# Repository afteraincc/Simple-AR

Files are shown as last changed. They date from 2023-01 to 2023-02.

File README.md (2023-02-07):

>
> 视频介绍：[Simple-AR百元AR眼镜](https://www.bilibili.com/video/BV1hj411M7NZ)
>

### 简介

一个`百元价位`的AR眼镜，用来学习了解AR的技术原理。基本流程：AR眼镜作为一个简单的显示设备，通过手机的`个人热点`连接到手机，然后手机通过`4G/5G`网络访问`互联网`，把需要的内容提供给AR眼镜显示出来。



AR眼镜粗略可分为几个子模块：

- 显示

	显示屏最好是既要分辨率高/亮度高/对比度高/色彩还原度高，又要体积小，还要耗电低/价格低。实际最后选择就一个：价格低...

- 光学

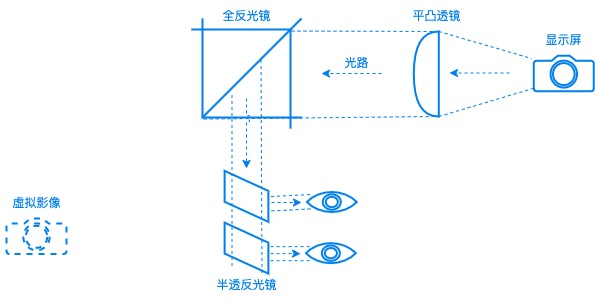
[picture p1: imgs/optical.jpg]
	

	- 平凸透镜

		原理是利用对点光源的准直`Collimating Light`特性，效果是可以避免影像重叠`Double Image Problem`。

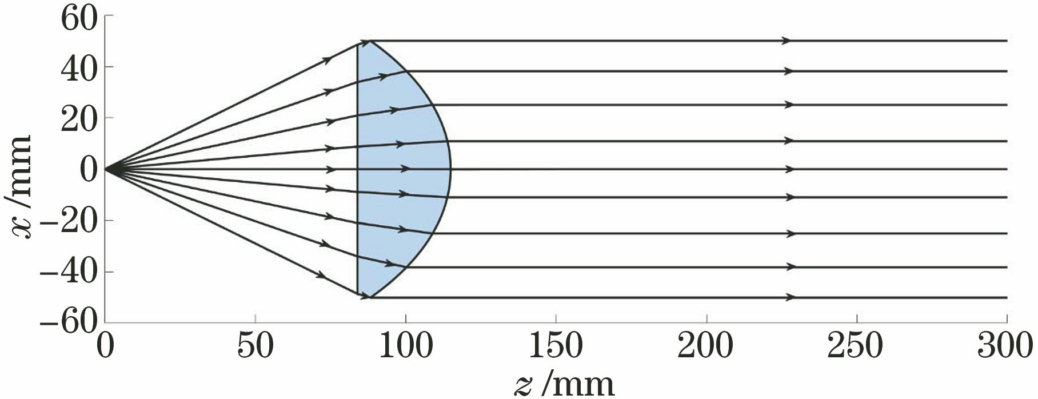
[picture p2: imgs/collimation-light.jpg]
		

		需要注意两点：
		
		- 安装时不要反了，遵循`点光对平面`：显示屏=>|平面/凸面)=>全反光镜

		- 透镜的位置：在保证显示区域的范围下尽量靠近焦点，这样准直光效果更好。但是也不能放在焦点上，否则无法成像...

	- 全反光镜

		为了避免影像重叠，最好采用单面镜`First Surface Mirrors`，而不是普通的玻璃镜`Second Surface Mirrors`。

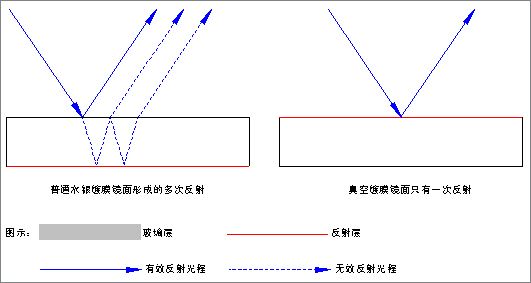
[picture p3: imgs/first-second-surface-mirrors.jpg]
		

	- 半透反光镜

		AR和VR的区别：AR既可以看到虚拟的影像，也可以看到真实的世界。镜片的厚度尽可能小，也可以避免重影现象。

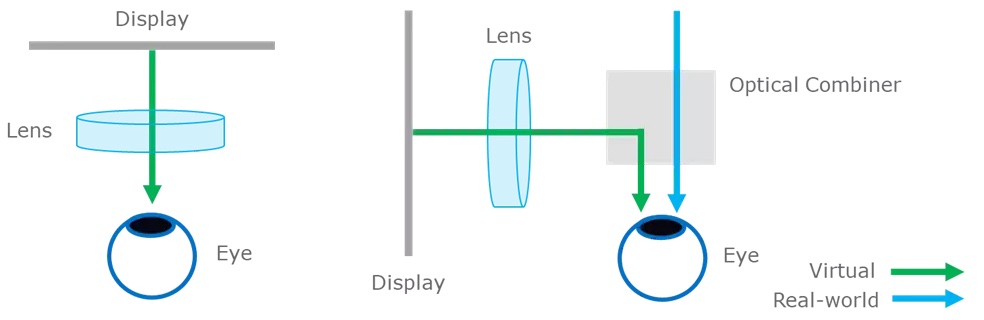
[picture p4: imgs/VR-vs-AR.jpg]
		
		
		注意的是：每个眼镜都对应一个半透反光镜。可以通过调整两个半透反光镜的角度，让虚像重叠形成立体图像效果。如果仅仅只有一个单眼观看时，容易出现不完整的图像现象，并且没有立体效果。

	- 比较一下苹果的专利方案

		使用了光波导`Waveguide`镜片，光路的原理都是一样的（显示=>准直光=>全反光=>半透反光）。

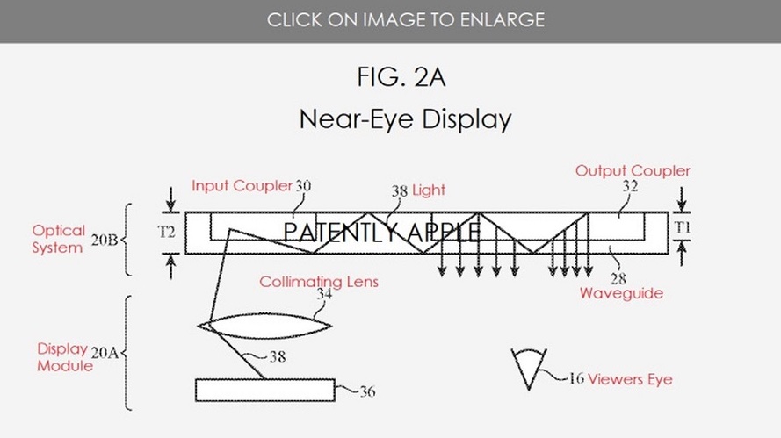
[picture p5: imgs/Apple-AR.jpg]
		

		光波导集成了全反光镜和半透反光镜，同时提供了一些新特性（例如一维/二维扩瞳技术提高视场角`FOV`）。

- 算力

	计算模块提供屏幕显示/图像压缩/无线传输等各种功能。一般用嵌入式设备，这样可以按需配置算力大小，以便压缩成本/定制尺寸。

- 电力

	穿戴设备面向移动场景，对电量的需求是越大越好，尺寸越小越好。

- 外框

	主要作用是固定各个组件以及方便的佩戴，在固定组件的位置时注意保证光路的中心对齐。使用3D打印技术能极大的降低成本。

### 材料清单和价格

都是选择淘宝上可以方便买到的东西，量足价低。

| 组件 | 价格（元） | 描述 |
| --- | --- | --- |
| 显示屏 | 17 | 1.3寸IPS屏240x240像素，SPI串口，ST7789驱动 |
| 平凸透镜 | 9.9 | 直径25mm焦距90mm |
| 全反光镜 | 8.5 | 软镜子/PVC镜面 50x50cm，实际只需要4.2x4.0cm |
| 半透反光镜 | 12.5 | 用显微镜的1mm载玻片(12.5元/50片)，也可以用更薄的0.15mm盖玻片（非常脆容易碎）  |
| 算力 | 19.5 | 开发板：NodeMCU-32S兼容Arduino，芯片模组：ESP-WROOM-32E |
| 框架 | 70 | 白色树脂3D打印 |
| 杜邦线 | 2 | 母对母 40根（实际使用8根） |
| 螺丝/螺母 | 4 | 亚克力材质 3x10mm 10套 |
| 总价 | 143.4 | |

### 值得改进的地方

其实每个部分都有非常大的改进空间，当然最后就是价格赶超各款在销的AR眼镜了。这个和项目的定位`百元价位`是冲突的，所以这些改进的地方也只是说说而已，并不会真正去改进的...

- 光学显示

	- 显示屏

		更高分辨率/更小尺寸。但是价格的增加不是一点点...240x240像素1.3寸IPS屏之只要17元，1920x1080像素0.39寸的OLED屏需要300～500元

	- 光波导`Waveguide`镜片

		重量轻，而且能提供更大的FOV。在alibaba.com搜索集成了显示屏的模组，1024x768分辨率要450刀，1920x1080分辨率要680刀...

	（显示区域原理： 焦距/直径）
光学显示系统（焦距固定/FOV/亮度等）/算力

	- 3D立体

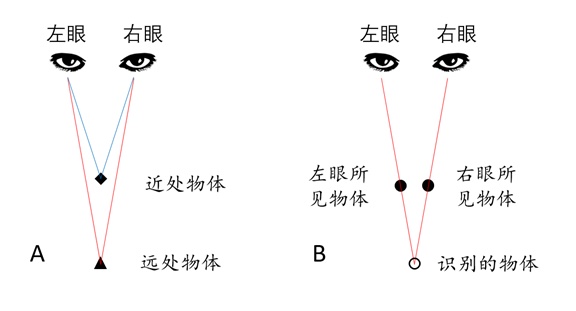
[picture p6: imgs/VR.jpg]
		

		人眼看到3D物体时，实际上左右眼看到的内容不一样，最后是通过大脑合成3D效果的。所以需要左右2路独立的显示模块，当然也需要更多的算力来生成相似但又有差异的画面，也需要更多的电力。
		
	- 混合现实`MR`

		大部分AR眼镜都是定焦成像，而眼睛的焦距调整范围比较广，如果看东西的焦距和眼镜的焦距差距比较大时，只能看到模糊的虚拟影像。
		
		- 可变焦距

			要清晰显示又贴近实物，就要集成可变/可调焦距的光学模块，有些类似手机/摄像机的自动对焦。

		- 眼球跟踪

			自动调焦配合眼球跟踪才能真正实现自动对焦。

	- 眼镜框

		另外树脂材料较软容易变形，可以考虑用硬度更高的尼龙材料，当然价格就要翻几倍了...

		为了方便携带，可以参考普通眼镜的结构（鼻托/耳架等）。为了美观，可以考虑加入钛合金，增加喷砂工艺，效果上升不止一个等级，当然价格也上升不止一个等级...

### 更实际一些的应用场景

**以下是纯属没有根据的瞎分析**

**主要是几点 1. 去掉内置电池 2. 有线替代无线 3. 眼镜只做显示设备，4. 算力需求移到人人都有/算力过剩的手机上。这样可以节省不少成本，也能减少体积，重量也更轻**

现在的AR眼镜价位在2～4千元，还主要是给第一批资金充足的尝鲜用户准备的。真要大规模推广，还是需要价格上相当的降低才行。所以可以考虑找一些要求不高，但是又有规模的用户场景来推广。

- 汽车HUD显示

	可玩性：有固定的电源，眼镜和手机都不需要考虑电不够的情况。而且手机作为算力来源，可玩性高太多了，手机上有非常成熟的语音控制/辅助驾驶/AR/VR等等各种现成的东西可用。

	价格：价格上应该比厂商集成的挡风玻璃（好几千）的便宜，还有一类外置的HUD价格也要500～1500。

	规模：公开市场分析估计各类的汽车HUD一年都有好几百万的销量，而且还在快速增长，还是有足够空间的

- 无人机HUD显示

	可用性：室外玩时已经带了一堆设备，无所谓多带一个高容量的充电宝了:-)
	
	价格：玩无人机的用户应该能接受稍贵一些的外设
	
	规模：估计大疆一家累计的就有几百万了吧？

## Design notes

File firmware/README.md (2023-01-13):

### 简介

需要有WIFI功能的嵌入式芯片，ESP32芯片是带WIFI功能中最常用的一款了。另外开发板选择了NodeMCU-32S，主要是兼容Arduino，资料多，方便开发。

### 网络连接流程

流程的关键步骤是`反向连接`：嵌入式设备非常不方便输入，所以由AR设备生成`个人热点`的SSID和密码，手机按照这个来配置热点。

- 如何重置`个人热点`配置

	先按`RESET`按键复位，然后快速按`IO0`按键，会重置配置，配置会显示在屏幕上。

### 内存

显示屏分辨率240x240，一张图需要的内存量： 240x240x2=115200字节。ESP32无法分配出这样大小的连续内存...（有方法能实现的，但是要魔改底层模块代码），所以无法使用常见的双帧方案来提高刷新率/并行处理。

### 性能

ESP32的性能对图像处理来说是不够的，测试下来解码240x240的JPEG也就8帧左右。

改成直接传输未压缩BMP图片，发现瓶颈出现在WIFI速率上，未优化的简单测试只能4帧/秒，3.5Mbps左右。查了一下[官方文档](https://docs.espressif.com/projects/esp-idf/en/latest/esp32/api-guides/wifi.html#esp32-wi-fi-throughput)能到20Mbps，但是需要重新编译内核参数等复杂操作。

### 视频流协议

ESP32的性能/内存等不满足一般的视频压缩流（例如MP4/H264等），选择最简单的MJPEG，实际上就是一张一张连续的JPEG图片。需要注意的是JPEG是一种压缩算法，压缩的码流数据要使用容器或文件格式进行 封装后保存或传输，参考[JFIF](https://www.w3.org/Graphics/JPEG/)

在传输的数据流中识别两种图片边界的关键点是JFIF规范了：

- 开头SOI`Start Of Image`对应十六进制 0xFFD8

- 结尾EOI`End Of Image`对应十六进制 0xFFD9

### 跳帧处理

主要还是内存不足（参考前面的`内存`部分）。JPEG的一般压缩率是10:1，但是最终是和图像复杂度有关系，内存申请上要稍微冗余多一点。即使这样也无法完全保证不出现不够的情况。

所以增加了跳帧的处理，如果JPEG图像过大时忽略。

方案选择的是在设备端实现，超出申请的内存时，从开头覆盖内存，但是保持结尾EOI的处理。而不是手机压缩时判断超出尺寸后忽略，避免耦合问题。

### 显示驱动TFT_eSPI库

配置分辨率/管针脚序号等时，官方提供的默认方案是修改库代码。这个方案对代码管理不友好，从上游更新一次代码，就需要记住手工修改一次库代码。

官方提供了另外一个较好的解决方案，任意目录下增加一个固定文件名`tft_setup.h`的配置文件。但是这个需要修改工程的编译参数才能实现，不同的IDE有不同的配置方法，所以最后在IDE层面又不统一了...

- Visual Studio Code + platformio

	配置文件`platformio.ini`增加`build_flags = -I include/tft`，然后`tft_setup.h`放在`include/tft`目录下

### TJpg_Decoder库

Visual Studio Code + platformio提供的TJpg_Decoder库版本非常低（只有0.2.0版本），代码中有inline函数，然后编译器无法兼容这种语法。这个库的新版本是解决了这个问题的，所以需要手工安装：同步TJpg_Decoder最新代码到`lib/TJpg_Decoder`目录即可

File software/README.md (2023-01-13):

### 简介

AR眼镜能看到手机屏幕上的任何内容。流程是录制手机屏幕，经过JPEG压缩，TCP协议传输到AR眼镜上，然后解压缩显示。

### 通用

- 屏幕尺寸

	AR眼镜的显示屏是240x240正方形，手机屏幕都是长方形，而且分辨率远高于240x240。所以只能截取部分屏幕（仅支持竖屏）：以短边（宽）作为正方形边，裁切手机上半部分的正方形内容，然后等比例缩放到240x240分辨率

- 个人热点

	手机开启热点

### Android

- 热点状态

	使用WifiManager实现

- 悬浮窗口

	申请悬浮窗口权限时，调用startActivityForResult，参数：Settings.ACTION_MANAGE_OVERLAY_PERMISSION。

- 录制屏幕

	使用MediaProjectionManager/MediaProjection/VirtualDisplay/ImageReader结合一个后台的IntentService来实现。
	
	Android的录制机制中，Service线程和屏幕数据线程不是一个，只要在函数`onHandleIntent`中实现截图/裁切/缩放/压缩/TCP发送的逻辑即可，其中的阻塞操作并不会影响屏幕数据（个人理解只是截图的acquireLatestImage一瞬间做了线程同步，确保正确采集到屏幕数据）

- 后台服务

	录制屏幕中有阻塞的TCP网络传输，需要使用Android的IntentService服务（普通的Service不能用耗时的阻塞操作）。

- Min SDK Version = 23

### iOS

- 个人热点

	iOS开启热点时，需要有SIM卡，并且运营商开通了热点权限。所以无SIM卡的手机就无法使用了。
	
	iOS热点不能直接配置，默认是手机名。所以如果要配置成AR眼镜的SSID，需要在`设置`=>`关于手机`=>`名称`进行修改。

	另外，iOS查询热点状态需要特殊扩展，个人账号（非开发者账号）没有权限使用，示例中只是写了代码，并没有验证。

- iOS Development Target = iOS 14.0

- 录制屏幕

	iOS的录制屏幕机制和Android不一样，更多的是类似视频流的机制，无论是否阻塞，屏幕数据流会按照固定速率（例如30帧/秒）持续发送到processSampleBuffer回调函数。如果在processSampleBuffer阻塞了，后续的屏幕数据都还在，就会导致帧的堆积，越来越慢。

	而且iOS网络库提供的NWConnection也是异步的机制，所以录制屏幕就不能用Android的同步阻塞机制，需要用`状态机`+`事件`的异步机制实现。

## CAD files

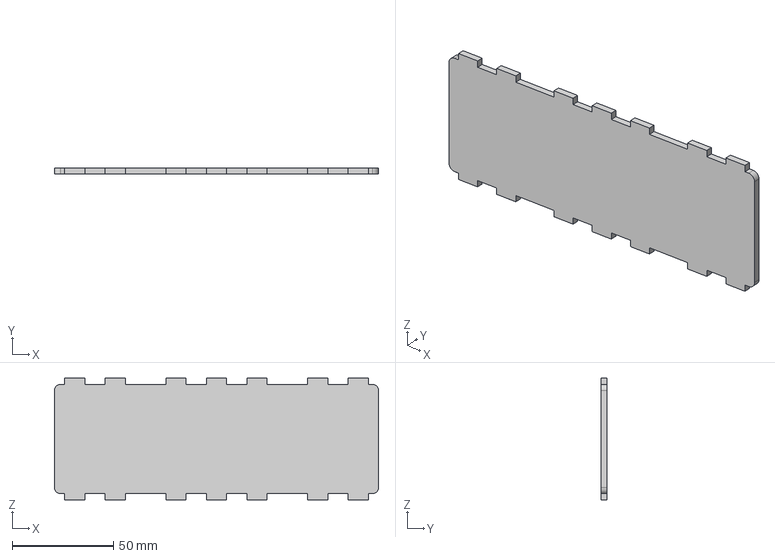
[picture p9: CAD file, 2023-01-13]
3d-model/debug/right.step
160.0 x 3.00 x 60.0 mm

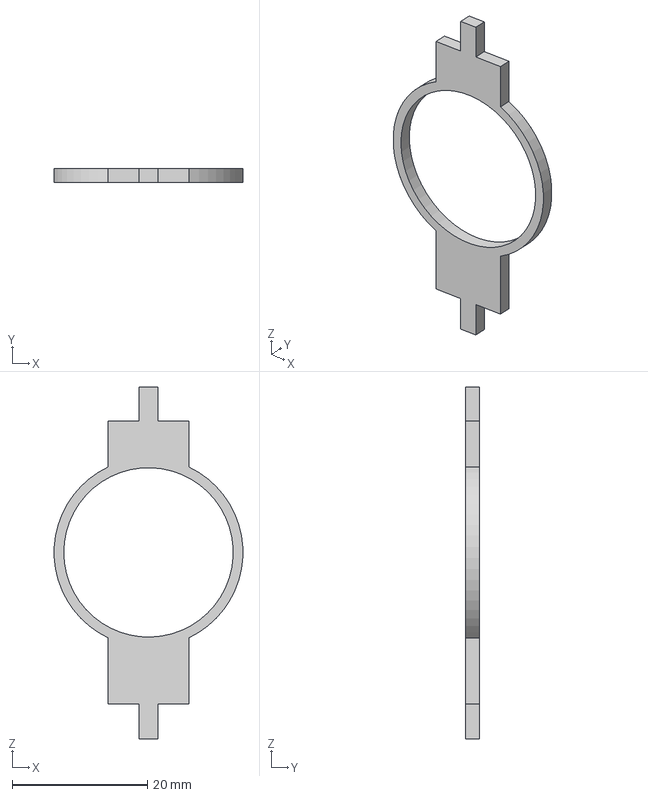
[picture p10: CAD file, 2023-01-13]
3d-model/lens.step
27.9 x 2.00 x 52.0 mm

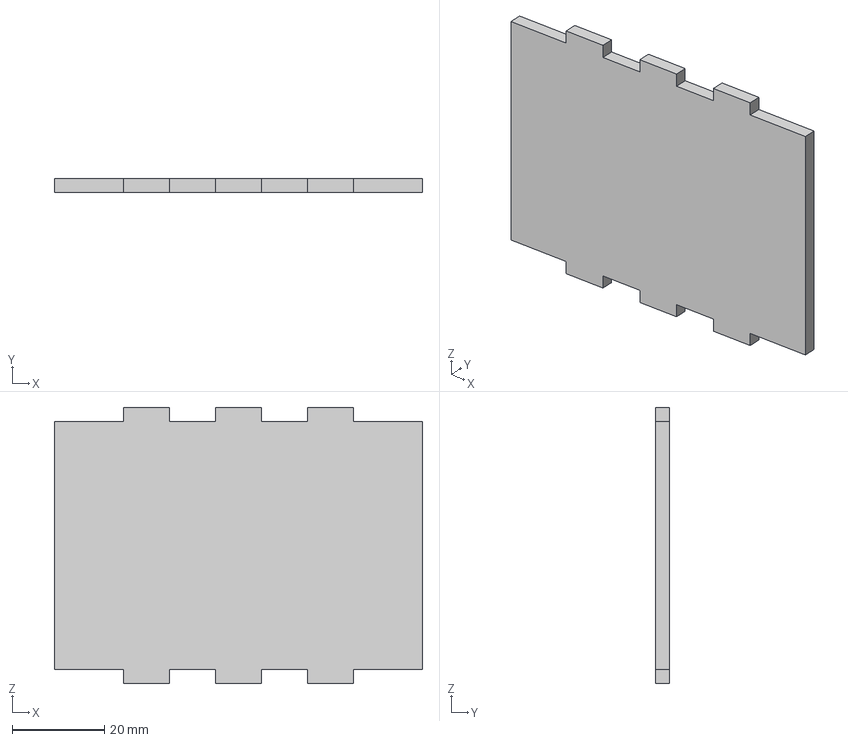
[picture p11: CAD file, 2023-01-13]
3d-model/debug/ear-right.step
80.0 x 3.00 x 60.0 mm

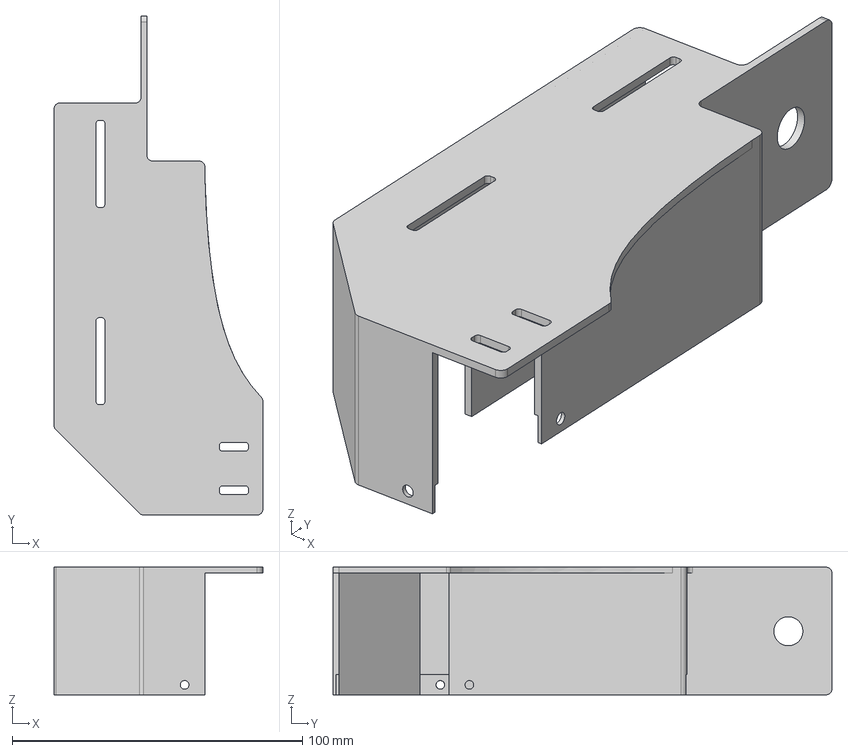
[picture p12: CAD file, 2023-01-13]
3d-model/right-top.step
72.0 x 172.0 x 44.0 mm

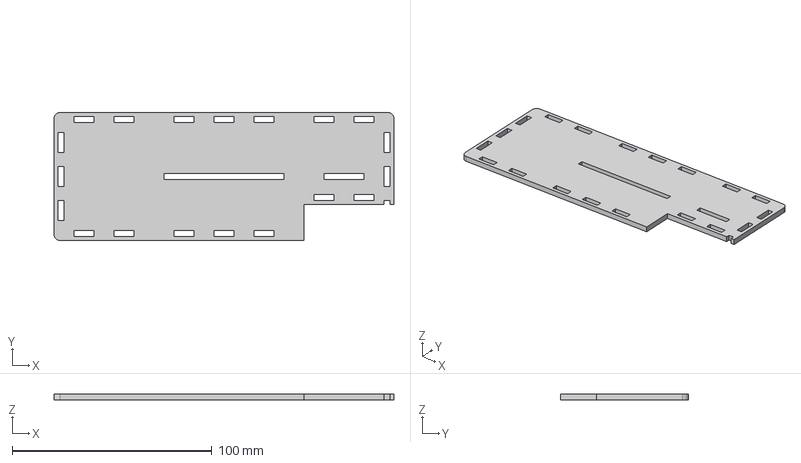
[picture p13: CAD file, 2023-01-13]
3d-model/debug/bottom.step
170.0 x 64.0 x 3.00 mm

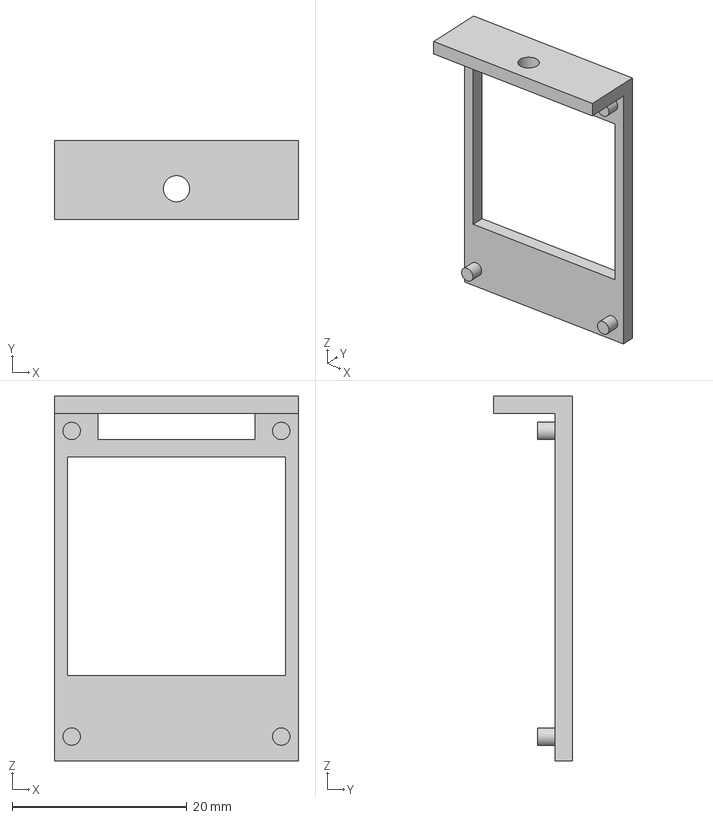
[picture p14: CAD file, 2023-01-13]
3d-model/display.step
28.0 x 9.00 x 41.8 mm

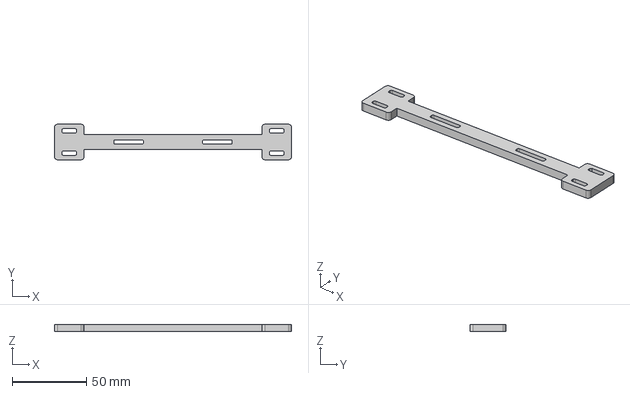
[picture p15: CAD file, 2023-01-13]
3d-model/beam-top.step
160.0 x 24.0 x 5.00 mm

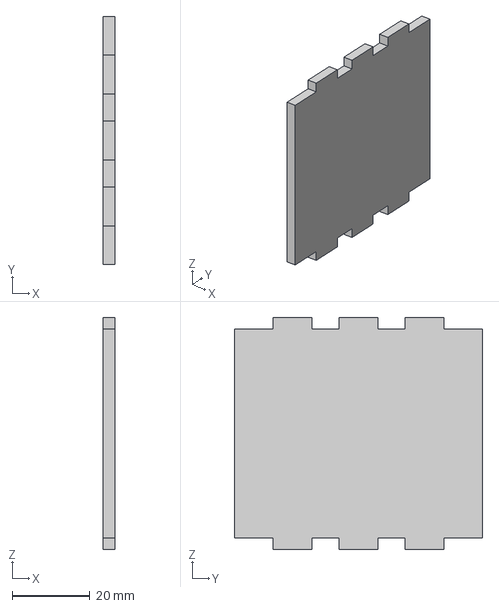
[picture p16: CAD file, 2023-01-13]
3d-model/debug/front.step
3.00 x 64.0 x 59.9 mm

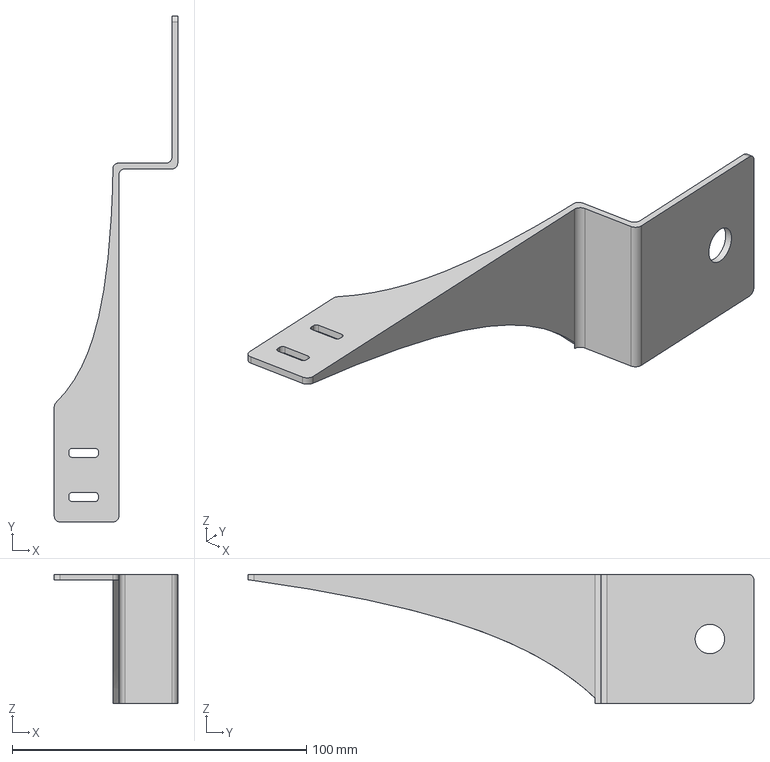
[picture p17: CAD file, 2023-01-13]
3d-model/left.step
42.0 x 172.0 x 44.0 mm

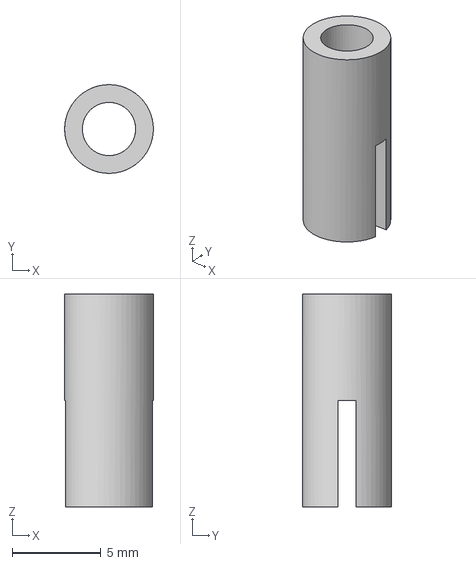
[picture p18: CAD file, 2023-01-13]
3d-model/beam-column-left.step
5.00 x 5.00 x 12.0 mm

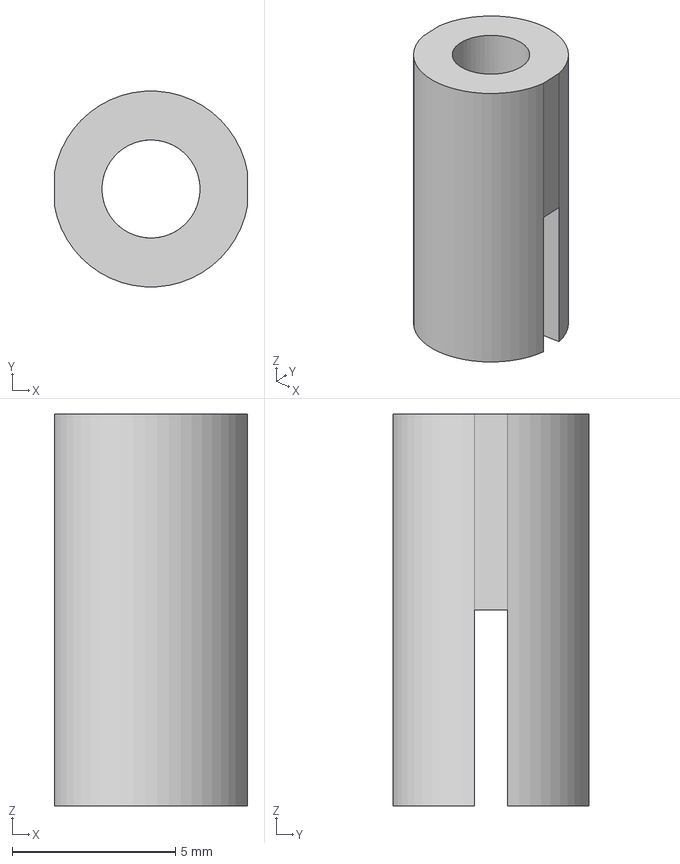
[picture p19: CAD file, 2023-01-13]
3d-model/debug/beam-column-1.step
5.92 x 5.99 x 12.0 mm

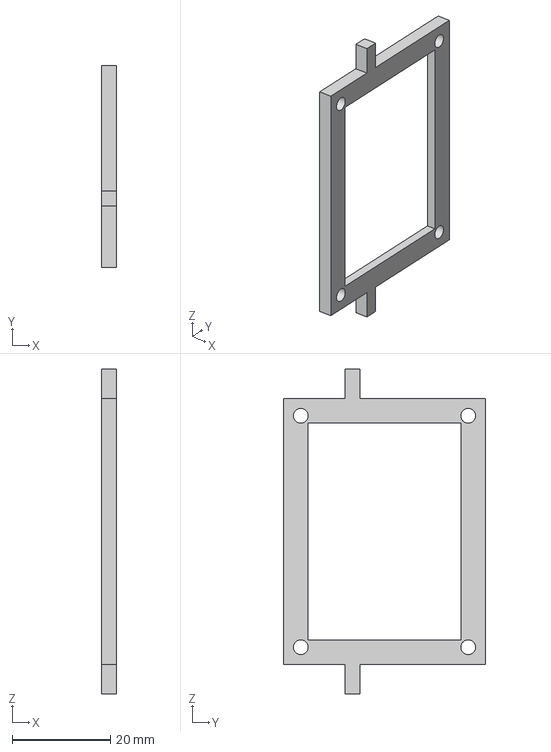
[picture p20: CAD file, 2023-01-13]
3d-model/debug/display-2.step
3.00 x 41.0 x 66.0 mm

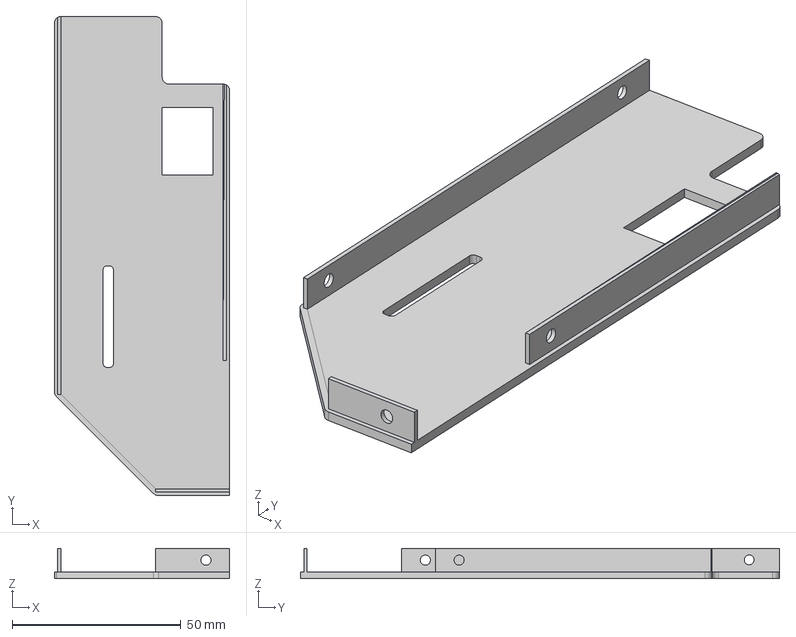
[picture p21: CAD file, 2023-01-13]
3d-model/right-bottom.step
52.0 x 142.0 x 9.00 mm

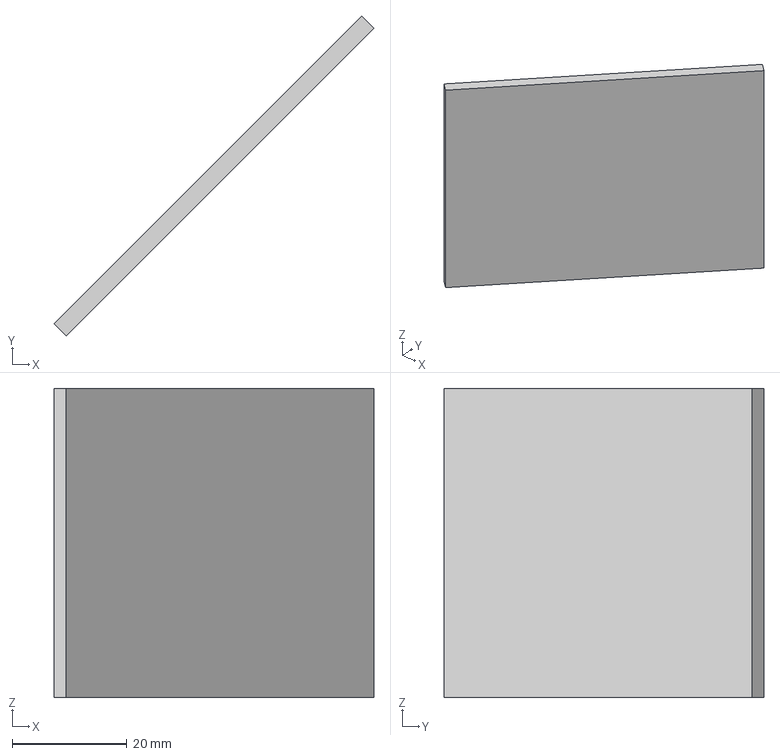
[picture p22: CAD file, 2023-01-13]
3d-model/debug/mirror.step
55.9 x 55.9 x 54.0 mm

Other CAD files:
3d-model/debug/ear-left.step
3d-model/beam-column-right.step
3d-model/debug/top.step
3d-model/debug/lens-2.step
3d-model/debug/back.step
3d-model/debug/beam-column-2.step
3d-model/debug/beam-top.step
3d-model/debug/display-1.step
3d-model/debug/display-beam.step
3d-model/debug/ear-bottom.step
3d-model/debug/ear-top.step
3d-model/debug/left.step
3d-model/debug/lens-1.step
3d-model/debug/lens-beam.step

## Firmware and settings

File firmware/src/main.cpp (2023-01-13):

#include <Arduino.h>
#include "tft_setup.h"
#include <TFT_eSPI.h>
#include <Esp.h>
#include <TJpg_Decoder.h>
#include <Preferences.h>
#include "frame_receiver.h"

static TFT_eSPI tft;
static WiFiServer server;

static String wifiName;
static String wifiPasswd;

static FrameReceiver *frameReciver = NULL;
static unsigned long recvTime = 0;

void echoSystemInfo()
{
  Serial.printf("chip revision: %d\n", ESP.getChipRevision());
  Serial.printf("chip model: %s\n", ESP.getChipModel());
  Serial.printf("chip cores: %d\n", ESP.getChipCores());
  Serial.printf("cpu FreqMHz: %d\n", ESP.getCpuFreqMHz());
  Serial.printf("sdk version: %s\n", ESP.getSdkVersion());

  Serial.printf("heap size: %d\n", ESP.getHeapSize());
  Serial.printf("free heap: %d\n", ESP.getFreeHeap());
  Serial.printf("mini free heap: %d\n", ESP.getMinFreeHeap());
  Serial.printf("max alloc heap: %d\n", ESP.getMaxAllocHeap());

  Serial.printf("psram size: %d\n", ESP.getPsramSize());
  Serial.printf("free psram: %d\n", ESP.getFreePsram());
  Serial.printf("mini free psram: %d\n", ESP.getMinFreePsram());
  Serial.printf("max alloc psram: %d\n", ESP.getMaxAllocPsram());
}

bool needConfigWiFi()
{
  return !digitalRead(KEY_BUILTIN);
}

void configWiFi()
{
  Preferences prefs;
  int r;
  prefs.begin("SimpleAR");

  wifiName = prefs.getString("WiFiName");
  wifiPasswd = prefs.getString("WiFiPasswd");
  if (needConfigWiFi() || wifiName.isEmpty() || wifiPasswd.isEmpty())
  {
    randomSeed(millis());

    wifiName = "AR-";
    // A-Z 65-90, a-z 97-122
    r = random(65, 90 - 4);
    for (int i = 0; i < 4; i++)
      wifiName += (char)(r + i);

    wifiPasswd = "";
    for (int i = 0; i < 4; i++)
    {
      r = random(97, 122);
      wifiPasswd += (char)(r);
      wifiPasswd += (char)(r - (97 - 65));
    }

    prefs.putString("WiFiName", wifiName);
    prefs.putString("WiFiPasswd", wifiPasswd);
  }

  prefs.end();
}

void displayWiFiProgress(const char *name, const char *passwd, int retryCount)
{
  int fontSize = 2;
  int lineHeight = fontSize * 8;
  int startX = tft.width() / 2;
  int startY = tft.height() / 2 - lineHeight;
  String t;

  tft.fillScreen(tft.color565(25, 25, 25));
  tft.setTextDatum(MC_DATUM);
  tft.setTextColor(TFT_WHITE, tft.color565(25, 25, 25));
  t = "WiFiName: ";
  t.concat(name);
  tft.drawString(t, startX, startY, fontSize);
  t = "WiFiPasswd: ";
  t.concat(passwd);
  tft.drawString(t, startX, startY + lineHeight, 2);
  t = "Retrying: ";
  t.concat(retryCount);
  tft.drawString(t, startX, startY + lineHeight * 2, 2);
}

void displayWiFiIP(const char *name, const char *passwd, const char *gateway, const char *ip)
{
  int fontSize = 2;
  int lineHeight = fontSize * 8;
  int startX = tft.width() / 2;
  int startY = tft.height() / 2 - lineHeight;
  String t;

  tft.fillScreen(tft.color565(25, 25, 25));
  tft.setTextDatum(MC_DATUM);
  tft.setTextColor(TFT_WHITE, tft.color565(25, 25, 25));
  t = "WiFiName: ";
  t.concat(name);
  tft.drawString(t, startX, startY, fontSize);
  t = "WiFiPasswd: ";
  t.concat(passwd);
  tft.drawString(t, startX, startY + lineHeight, 2);
  t = "Gateway: ";
  t.concat(gateway);
  tft.drawString(t, startX, startY + lineHeight * 2, 2);
  t = "IP: ";
  t.concat(ip);
  tft.drawString(t, startX, startY + lineHeight * 3, 2);
}

void connectWiFi()
{
  int retryCount = 0;
  WiFi.mode(WIFI_STA);
  WiFi.begin(wifiName.c_str(), wifiPasswd.c_str());

  Serial.println("Waiting for WiFi");
  Serial.println("name: " + wifiName);
  Serial.println("passwd: " + wifiPasswd);
  displayWiFiProgress(wifiName.c_str(), wifiPasswd.c_str(), retryCount);
  while (WiFi.status() != WL_CONNECTED)
  {
    delay(2000);
    Serial.print(".");
    retryCount++;
    displayWiFiProgress(wifiName.c_str(), wifiPasswd.c_str(), retryCount);
  }
  Serial.println("");
  Serial.println("WiFi connected.");

  Serial.print("Gateway: ");
  Serial.println(WiFi.gatewayIP());
  Serial.print("IP Address: ");
  Serial.println(WiFi.localIP());

  displayWiFiIP(wifiName.c_str(), wifiPasswd.c_str(),
                WiFi.gatewayIP().toString().c_str(),
                WiFi.localIP().toString().c_str());
}

bool tft_output(int16_t x, int16_t y, uint16_t w, uint16_t h, uint16_t *bitmap)
{
  if (y >= tft.height())
    return 0;
  tft.pushImage(x, y, w, h, bitmap);
  return 1;
}

void initScreen()
{
  TFT_eSPI tft = TFT_eSPI();
  tft.init();
  tft.fillScreen(tft.color565(255, 255, 255));

  TJpgDec.setSwapBytes(true);
  TJpgDec.setCallback(tft_output);
}

void beginTCPServer()
{
  server.setNoDelay(true);
  server.begin(12345);
}

void setup()
{
  Serial.begin(115200);
  echoSystemInfo();

  initScreen();
  configWiFi();
  connectWiFi();

  beginTCPServer();
}

void createFrameReceiver()
{
  if (server.hasClient())
  {
    if (NULL == frameReciver)
    {
      frameReciver = new FrameReceiver(&server);
      Serial.println("new receiver");
    }
    else
    {
      Serial.println("delete receiver by new peer");
      delete frameReciver;
      frameReciver = NULL;
      frameReciver = new FrameReceiver(&server);
      Serial.println("new receiver");
    }
    recvTime = millis();
  }

  if (NULL != frameReciver && !frameReciver->connected())
  {
    Serial.println("receiver disconnect by peer");
    delete frameReciver;
    frameReciver = NULL;
  }
  if (NULL != frameReciver && (millis() - recvTime > 60000))
  {
    Serial.println("receiver disconnect by timeout");
    delete frameReciver;
    frameReciver = NULL;
  }
}

void loop()
{
  uint32_t recvBytes = 0;

  createFrameReceiver();
  if (NULL == frameReciver)
  {
    delay(1);
    return;
  }

  // maybe more than one frame
  while (true)
  {
    recvBytes = frameReciver->recvData();
    if (recvBytes <= 0)
    {
      if (recvBytes < 0)
        Serial.printf("recvBytes < 0\n");
      break;
    }
    recvTime = millis();
    Serial.printf("recvBytes: %d, recvTime: %d\n", recvBytes, recvTime);

    if (frameReciver->hasFrame())
    {
      Serial.printf("drawJpg: skip %d, size %d\n", frameReciver->isSkippedFrame(), frameReciver->frameSize());
      if (!frameReciver->isSkippedFrame())
      {
        // draw it
        TJpgDec.drawJpg(0, 0, frameReciver->frameData(), frameReciver->frameSize());
      }
      frameReciver->nextFrame();
      frameReciver->sendAck();
    }
  }
}

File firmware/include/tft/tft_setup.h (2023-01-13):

#define ST7789_DRIVER // Full configuration option, define additional parameters below for this display

#define TFT_WIDTH 240  // ST7789 240 x 240 and 240 x 320
#define TFT_HEIGHT 240 // ST7789 240 x 240

#define TFT_MOSI 23
#define TFT_SCLK 18
//#define TFT_CS 5  // Chip select control pin
#define TFT_DC 26  // Data Command control pin
#define TFT_RST 25 // Reset pin (could connect to Arduino RESET pin)
#define TFT_BL 27  // LED back-light (required for M5Stack)

#define LOAD_GLCD  // Font 1. Original Adafruit 8 pixel font needs ~1820 bytes in FLASH
#define LOAD_FONT2 // Font 2. Small 16 pixel high font, needs ~3534 bytes in FLASH, 96 characters
#define LOAD_FONT4 // Font 4. Medium 26 pixel high font, needs ~5848 bytes in FLASH, 96 characters
#define LOAD_FONT6 // Font 6. Large 48 pixel font, needs ~2666 bytes in FLASH, only characters 1234567890:-.apm
#define LOAD_FONT7 // Font 7. 7 segment 48 pixel font, needs ~2438 bytes in FLASH, only characters 1234567890:-.
#define LOAD_FONT8 // Font 8. Large 75 pixel font needs ~3256 bytes in FLASH, only characters 1234567890:-.
#define LOAD_GFXFF // FreeFonts. Include access to the 48 Adafruit_GFX free fonts FF1 to FF48 and custom fonts
// Comment out the #define below to stop the SPIFFS filing system and smooth font code being loaded
// this will save ~20kbytes of FLASH
#define SMOOTH_FONT

#define SPI_FREQUENCY 27000000
// Optional reduced SPI frequency for reading TFT
#define SPI_READ_FREQUENCY 20000000
// The XPT2046 requires a lower SPI clock rate of 2.5MHz so we define that here:
#define SPI_TOUCH_FREQUENCY 2500000

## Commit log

2023-01-13 initial code
    [back.step, beam-column-1.step, beam-column-2.step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]
2023-02-07 增加B站视频
